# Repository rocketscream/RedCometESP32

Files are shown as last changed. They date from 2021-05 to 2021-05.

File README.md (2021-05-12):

# Red Comet ESP32
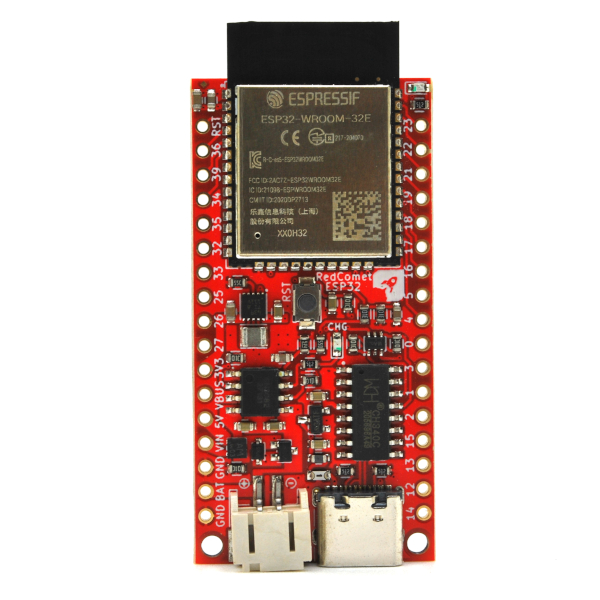
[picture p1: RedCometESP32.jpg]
Red Comet ESP32

An ultra low power ESP32 board. The board is able to run from variety type of battery below and above it's 3.3V operating voltage. This allow batteries such as 3xNiMH or 4xNiMH, Li-Ion/Pol, 3 or 4 alkaline and LiFePO4 to be used. Board sleep at 13.0 uA with charger off.

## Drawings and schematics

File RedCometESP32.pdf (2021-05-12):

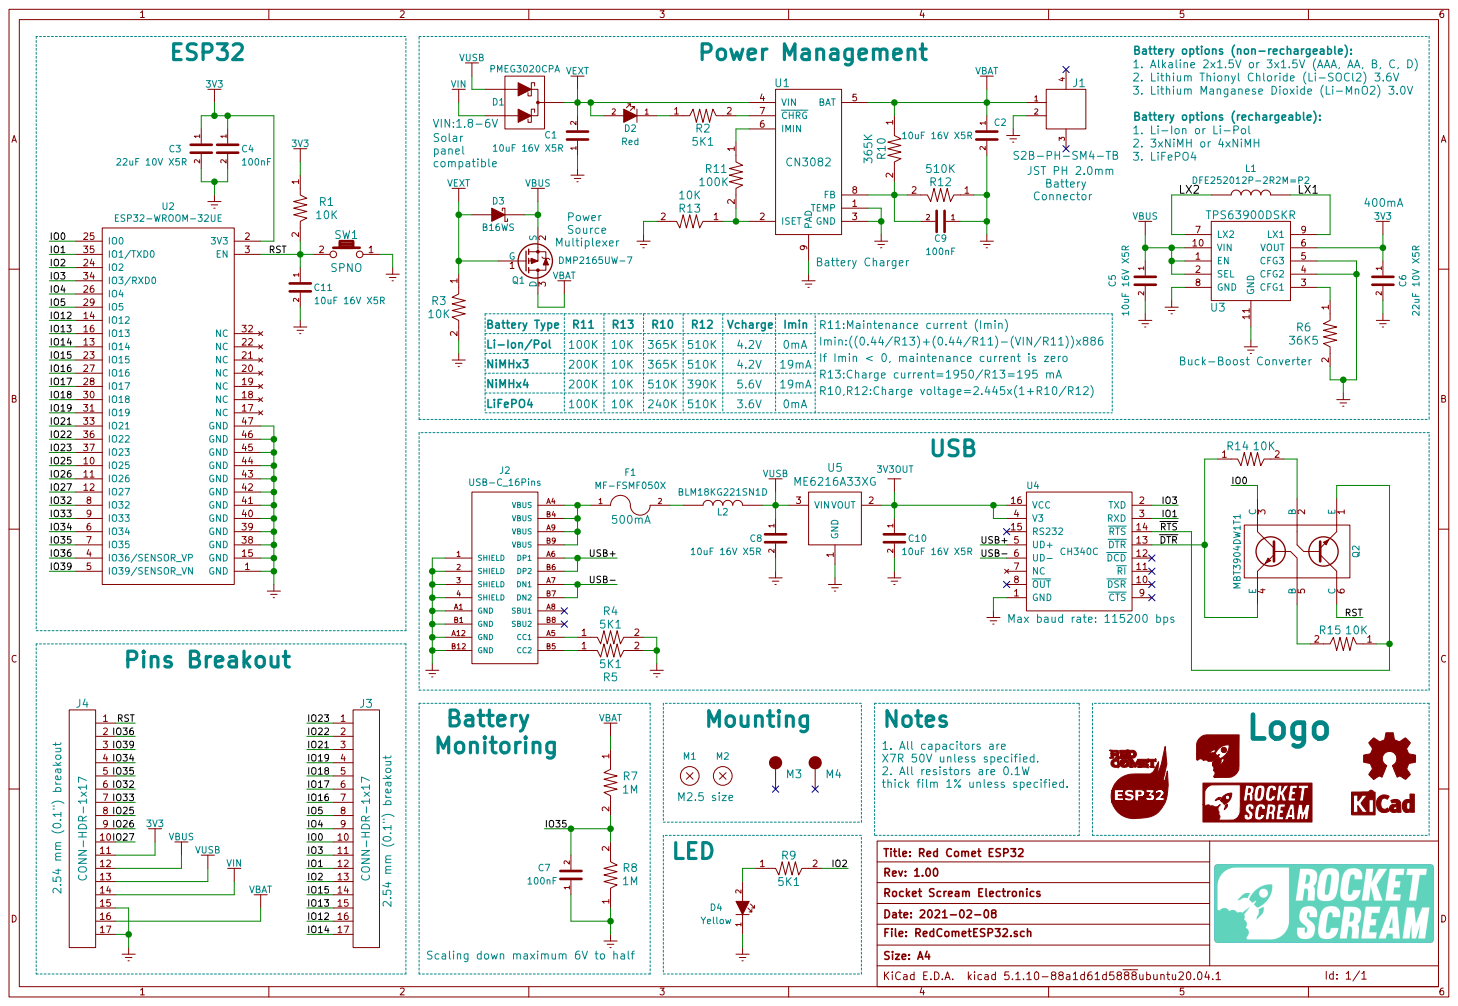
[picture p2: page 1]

2. Lithium Thionyl Chloride (Li-SOCl2) 3.6V

Battery Type | R11 | R13 | Vcharge | Imin | R11:Maintenance current (Imin) R13:Charge current=1950/R13=195 mA

Imin:((0.44/R13)+(0.44/R11)-(VIN/R11))x886
If Imin < 0, maintenance current is zero

4.2V | | R10,R12:Charge voltage=2.445x(1+R10/R12) 365K

5.6V | 19mA
3.6V

1. All capacitors are
X7R 50V unless specified. 2. All resistors are 0.1W

thick film 1% unless specified.

Id: 1/1 Title: Red Comet ESP32 File: RedCometESP32.sch Rocket Scream Electronics
D Date: 2021-02-08 KiCad E.D.A. kicad 5.1.10-88a1d61d5888ubuntu20.04.1 Rev: 1.00 Size: A4

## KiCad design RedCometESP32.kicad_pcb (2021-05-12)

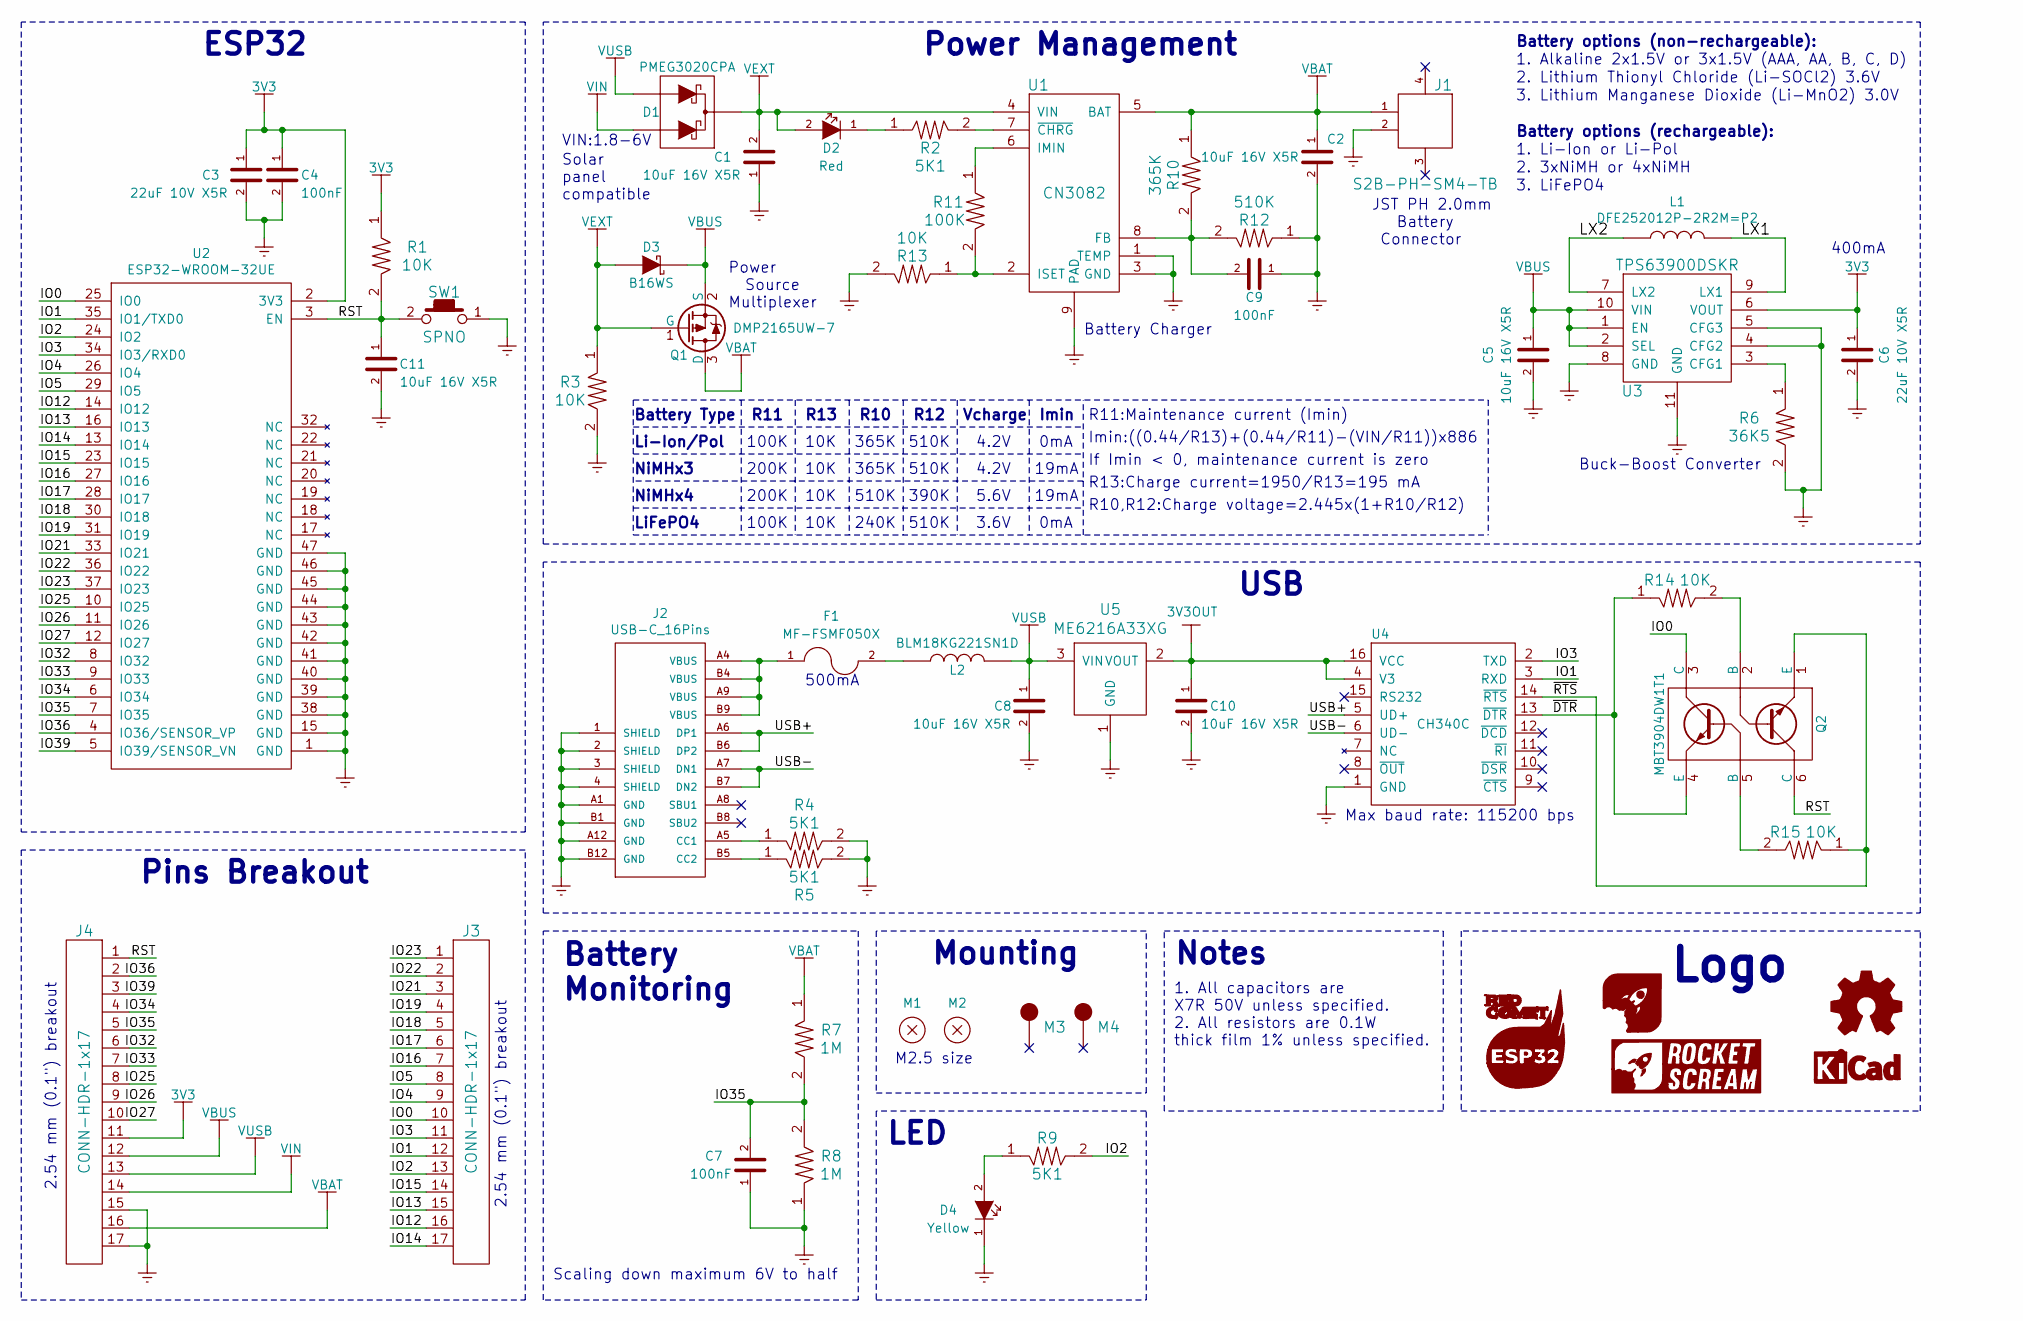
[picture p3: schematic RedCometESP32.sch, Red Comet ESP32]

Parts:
C1, C2, C5, C8, C10, C11: 10uF 16V X5R; C_0603
C3, C6: 22uF 10V X5R; C_0603
C4, C7, C9: 100nF; C_0603
D1: PMEG3020CPA; SOT-1016
D2: Red; LED_0603
D3: B16WS; SOD-323
D4: Yellow; LED_0603
F1: MF-FSMF050X; MF-FSMF
J1: S2B-PH-SM4-TB
J2: USB-C_16Pins; USB-TYPE-C-16PIN-SMD
J3, J4: CONN-HDR-1x17; HDR_1x17_Pitch2.54mm_WithoutSilk_SmallerPads
L1: DFE252012P-2R2M=P2; DFE2520
L2: BLM18KG221SN1D; I_0603
LOGO1: LOGO-OSHW; LOGO-OSHW_XXSmall
LOGO2: LOGO-KICAD; LOGO-KICAD_XSmall
LOGO3: LOGO-ROCKET-SCREAM-HORIZONTAL; LOGO-ROCKET-SCREAM_Horizontal_XXSmall
LOGO4: LOGO-ROCKET-SCREAM-WITHOUT-TEXT; LOGO-ROCKET-SCREAM_Without_Text_XXXXSmall
LOGO5: LOGO-RED-COMET-ESP32; LOGO-RED-COMET-ESP32_Large
M1, M2: MOUNT_HOLE; HOLE_NPTH_2.2MM
M3, M4: FIDUCIAL; FIDUCIAL-0.5MM_SQUARE
Q1: DMP2165UW-7; SOT-323
Q2: MBT3904DW1T1; SOT-363_ON_Semi
R1, R3, R13, R14, R15: 10K; R_0603
R2, R4, R5, R9: 5K1; R_0603
R6: 36K5; R_0603
R7, R8: 1M; R_0603
R10: 365K; R_0603
R11: 100K; R_0603
R12: 510K; R_0603
SW1: SPNO; TS-107A
U1: CN3082; SOIC-8-N_8S1_ThermalPad
U2: ESP32-WROOM-32UE; ESP32-WROOM-32UE_ShorterPads
U3: TPS63900DSKR; WSON-10
U4: CH340C; SOP-16_150mil
U5: ME6216A33XG; SOT-23

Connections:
3V3: C3.1, C4.1, C6.1, J4.11, R1.1, U2.2 (3V3), U3.6 (VOUT)
3V3OUT: C10.1, U4.4 (V3), U4.16 (VCC), U5.2 (VOUT)
/IO0: J3.10, Q2.3 (C), U2.25 (IO0)
/IO1: J3.12, U2.35 (IO1/TXD0), U4.3 (RXD)
/IO2: J3.13, R9.2, U2.24 (IO2)
/IO3: J3.11, U2.34 (IO3/RXD0), U4.2 (TXD)
/IO4: J3.9, U2.26 (IO4)
/IO5: J3.8, U2.29 (IO5)
/IO12: J3.16, U2.14 (IO12)
/IO13: J3.15, U2.16 (IO13)
/IO14: J3.17, U2.13 (IO14)
/IO15: J3.14, U2.23 (IO15)
/IO16: J3.7, U2.27 (IO16)
/IO17: J3.6, U2.28 (IO17)
/IO18: J3.5, U2.30 (IO18)
/IO19: J3.4, U2.31 (IO19)
/IO21: J3.3, U2.33 (IO21)
/IO22: J3.2, U2.36 (IO22)
/IO23: J3.1, U2.37 (IO23)
/IO25: J4.8, U2.10 (IO25)
/IO26: J4.9, U2.11 (IO26)
/IO27: J4.10, U2.12 (IO27)
/IO32: J4.6, U2.8 (IO32)
/IO33: J4.7, U2.9 (IO33)
/IO34: J4.4, U2.6 (IO34)
/IO35: C7.2, J4.5, R7.2, R8.2, U2.7 (IO35)
/IO36: J4.2, U2.4 (IO36/SENSOR_VP)
/IO39: J4.3, U2.5 (IO39/SENSOR_VN)
/LX1: L1.2, U3.9 (LX1)
/LX2: L1.1, U3.7 (LX2)
/RST: C11.1, J4.1, Q2.6 (C), R1.2, SW1.2, U2.3 (EN)
/USB+: J2.A6 (DP1), J2.B6 (DP2), U4.5 (UD+)
/USB-: J2.A7 (DN1), J2.B7 (DN2), U4.6 (UD-)
/~DTR~: Q2.4 (E), R14.1, U4.13 (~DTR)
/~RTS~: Q2.1 (E), R15.1, U4.14 (~RTS)
GND: C1.1, C2.2, C3.2, C4.2, C5.2, C6.2, C7.1, C8.2, C9.1, C10.2, C11.2, D4.1 (K), J1.2, J2.1 (SHIELD), J2.2 (SHIELD), J2.3 (SHIELD), J2.4 (SHIELD), J2.A1 (GND), J2.A12 (GND), J2.B1 (GND), J2.B12 (GND), J4.15, J4.17, R3.2, R4.2, R5.2, R6.2, R8.1, R12.1, R13.2, SW1.1, U1.1 (TEMP), U1.3 (GND), U1.9 (PAD), U2.1 (GND), U2.15 (GND), U2.38 (GND), U2.39 (GND), U2.40 (GND), U2.41 (GND), U2.42 (GND), U2.43 (GND), U2.44 (GND), U2.45 (GND), U2.46 (GND), U2.47 (GND), U3.4 (CFG2), U3.5 (CFG3), U3.8 (GND), U3.11 (GND), U4.1 (GND), U5.1 (GND)
unnamed: C9.2, R10.2, R12.2, U1.8 (FB)
unnamed: D2.1 (K), R2.1
unnamed: D4.2 (A), R9.1
unnamed: F1.1, J2.A4 (VBUS), J2.A9 (VBUS), J2.B4 (VBUS), J2.B9 (VBUS)
unnamed: F1.2, L2.1
unnamed: J2.A5 (CC1), R4.1
unnamed: J2.B5 (CC2), R5.1
unnamed: Q2.2 (B), R14.2
unnamed: Q2.5 (B), R15.2
unnamed: R2.2, U1.7 (~CHRG~)
unnamed: R6.1, U3.3 (CFG1)
unnamed: R11.1, U1.6 (IMIN)
unnamed: R11.2, R13.1, U1.2 (ISET)
VBAT: C2.1, J1.1, J4.16, Q1.3 (D), R7.1, R10.1, U1.5 (BAT)
VBUS: C5.1, D3.1 (K), J4.12, Q1.2 (S), U3.1 (EN), U3.2 (SEL), U3.10 (VIN)
VEXT: C1.2, D1.3 (K), D2.2 (A), D3.2 (A), Q1.1 (G), R3.1, U1.4 (VIN)
VIN: D1.2 (A), J4.14
VUSB: C8.1, D1.1 (A), J4.13, L2.2, U5.3 (VIN)

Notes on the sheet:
Logo
Mounting
Pins Breakout
LED
Battery Charger
USB
ESP32
VIN:1.8-6V
Notes
1. All capacitors are X7R 50V unless specified. 2. All resistors are 0.1W thick film 1% unless specified.
M2.5 size
2.54 mm (0.1") breakout
500mA
Battery Monitoring
Scaling down maximum 6V to half
JST PH 2.0mm Battery Connector
Solar panel compatible
Power Source Multiplexer
Buck-Boost Converter
400mA
Battery options (rechargeable):
1. Li-Ion or Li-Pol
2. 3xNiMH or 4xNiMH
3. LiFePO4
Battery options (non-rechargeable):
1. Alkaline 2x1.5V or 3x1.5V (AAA, AA, B, C, D)
3. Lithium Manganese Dioxide (Li-MnO2) 3.0V
Power Management
Battery Type
Li-Ion/Pol
NiMHx3
NiMHx4
LiFePO4
R11
R13
R10
R12
100K
200K
10K

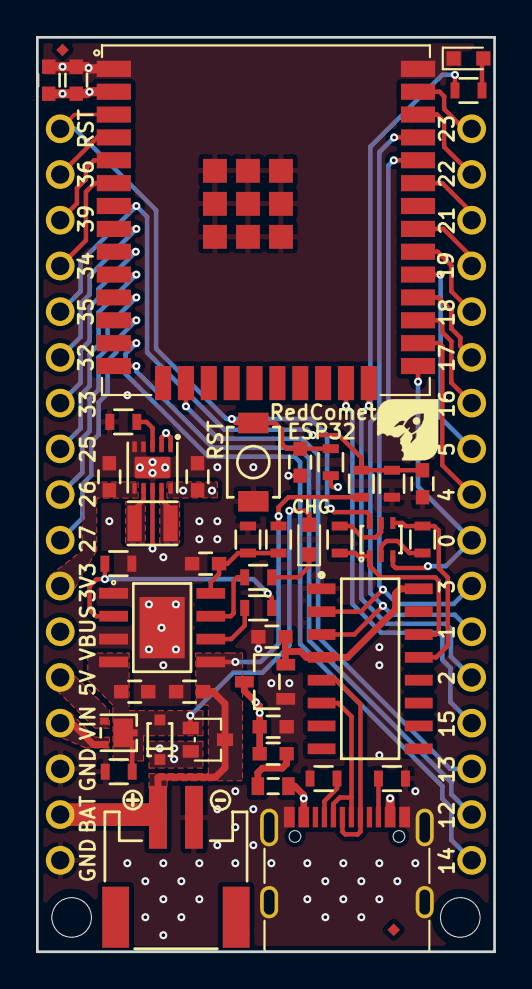
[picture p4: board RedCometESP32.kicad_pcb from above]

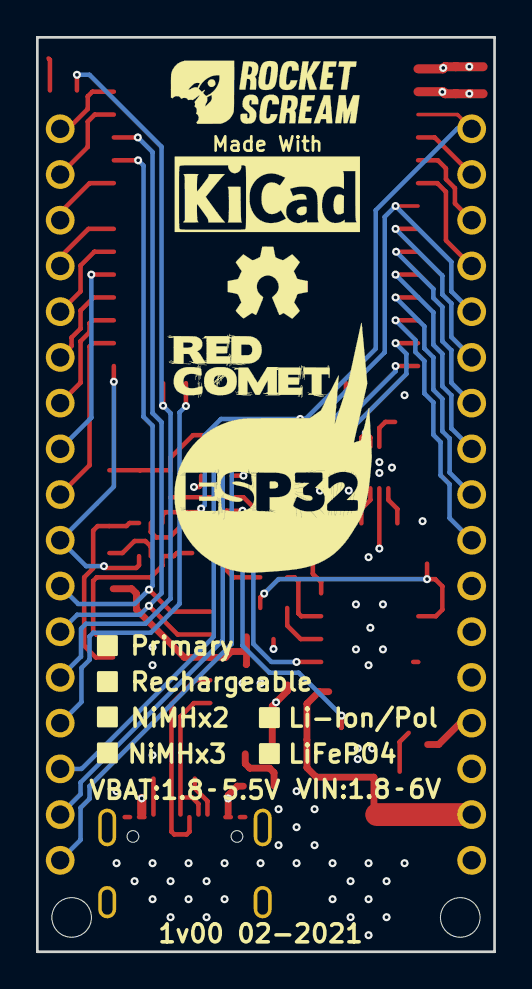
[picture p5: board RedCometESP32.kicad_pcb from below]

Board: 4 copper layers, 25.4 x 50.8 mm, 54 parts (6 on the bottom side), 54 nets.
